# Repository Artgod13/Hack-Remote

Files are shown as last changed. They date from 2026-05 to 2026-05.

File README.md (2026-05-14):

# Hack-Remote
A cool remote that lets you control RF signals with a CC1101 module.
It has been specifically designed with customibilty in the code and ease of use in mind.
(Be careful to follow all radio laws in your area of jurisdiction)


 ---
 How this works is when you plug it into a power source to turn it on, you open up to a menu of different Mhz frequencies. At this menu you can scroll through different Mhz frequencies and click the rotary encoder switch to send out you're desired signal. I also added a signal called 676767 (Really funny I know). When you choose this signal it sends out the same message on 50 randomly chosen Mhz frequencies on at a time in quick succession to "test" RF signal receivers. I have made the code simple and easy to understand so that someone can go in and add their own desired Mhz frequencies and messages.
 
 ---
 I decided to make this, as I am constantly surrounded by RF receivers and transmitors. So why not build a simple device that is kinda like a flipper zero, and can manipulate/work with these RF signals. (Also flipper zeros are super expensive so if you want to make one but for like only RF here you go!)
 
 ---
 # Build Instructions:
Assembling the Hack Remote is very simple, all you need is a soldering iron, solder, 3d printed parts, PCB board, and all the parts in the BOM. First get the PCB board and place the compoments all facing up, and solder them onto their designated spots one by one. Next you want to flash the code onto the board, you do this by opening arduino IDE opening the code selecting the Xiao RP2040, and installing the Adafruit BusIO, AdafruitGFX Library, AdafruitSSD1306, RotaryEncoder, and SmartRC-CC1101-Driver-Lib Libraries. Then connnect you're board to the computer, and click upload on ArduinoIDE. After this get the Hack Remote bottom 3d printed part and put the assembled board onto it so that the Xiao usb-c end can be seen sticking out the power hole. Then screw the board on using 2 screws to make sure it stays in place. Finally put the Hack Remote Top on top of the bottom piece and use the rest of the screws to screw it in place. After all this work you should finally have a assembled Hack Remote ready to be used.

 ---
 # CAD MODEL:
 

These models were fully designed, and assembled in onshape.
https://cad.onshape.com/documents/6f64acb43278fcf02d95f203/w/43ea7b20cd107b410569e89b/e/a30772a52d9b3aa84b86adaa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

---
# PCB:



These were fully made on KiCad

---

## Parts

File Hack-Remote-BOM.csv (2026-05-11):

Item | Quantity | Unit Price ($) | Total Price ($) | URL
M3 x 8mm | 6 | 0.32 | 1.92 | https://accu-components.com/us/countersunk-socket-head-screws/5423-SSK-M3-8-A2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
EC11 Rotary Encoder | 1 | 2.27 | 2.27 | https://www.digikey.com/en/products/detail/bourns-inc/PEC11R-4220F-S0024/4499660
Seeed XIAO RP2040 | 1 | 3.99 | 3.99 | https://www.seeedstudio.com/XIAO-RP2040-v1-0-p-5026.html
0.91" 128x32 OLED Display | 1 | 3.73 | 3.73 | https://www.robotshop.com/products/091-inch-128x32-i2c-oled-display-blue
CC1101 | 1 | 8.99 | 8.99 | https://www.amazon.com/MELIFE-CC1101-Wireless-Antenna-Transceiver/dp/B0F7XGBX65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
Grand Total: 20.9

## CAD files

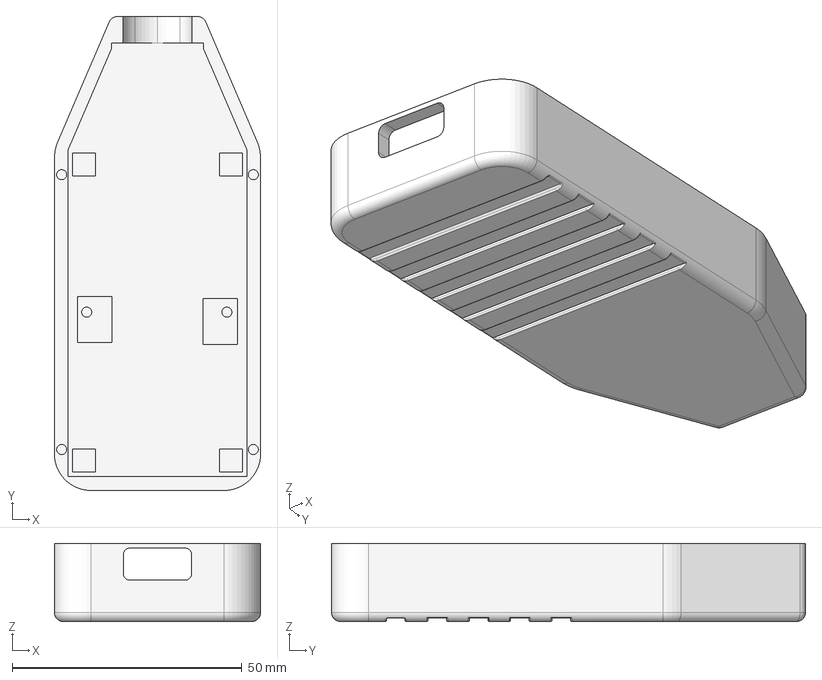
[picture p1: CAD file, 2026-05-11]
CAD/Hack-Remote-Top.step
44.9 x 103.1 x 17.0 mm

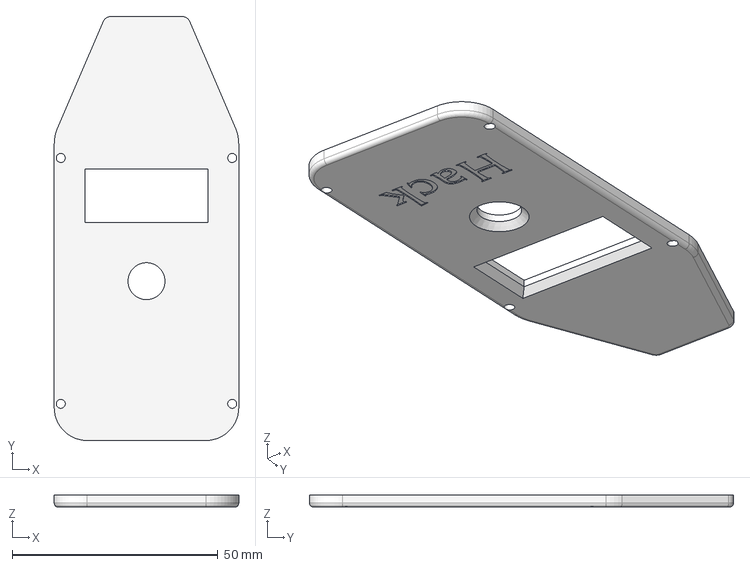
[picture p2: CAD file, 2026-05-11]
CAD/Hack-Remote-Bottom.step
44.9 x 103.1 x 3.00 mm

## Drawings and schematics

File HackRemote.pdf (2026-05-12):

# Hack Remote

# Arthur Bain 16 US

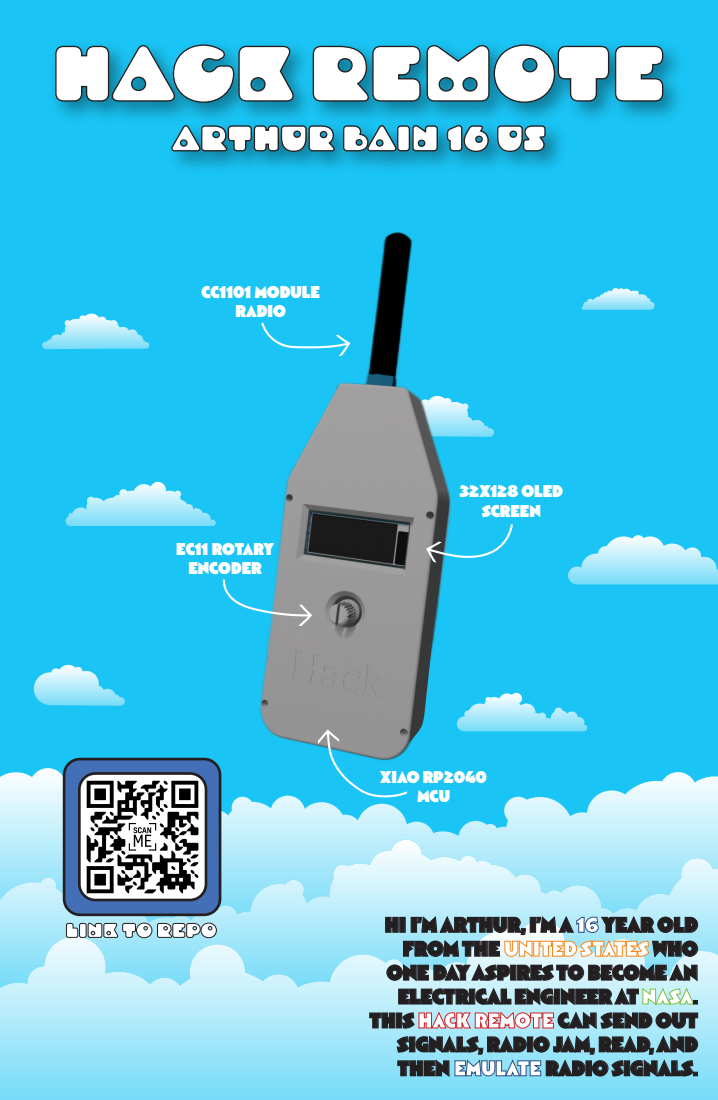
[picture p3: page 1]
CC1101 MODULE RADIO; 32X128 OLED SCREEN; EC11 ROTARY ENCODER; XIAO RP2040 MCU

LINK TO REPO

HI I’M ARTHUR, I’M A 16 YEAR OLD
FROM THE UNITED STATES WHO
ONE DAY ASPIRES TO BECOME AN
ELECTRICAL ENGINEER AT NASA.
THIS HACK REMOTE CAN SEND OUT
SIGNALS, RADIO JAM, READ, AND
THEN EMULATE RADIO SIGNALS.

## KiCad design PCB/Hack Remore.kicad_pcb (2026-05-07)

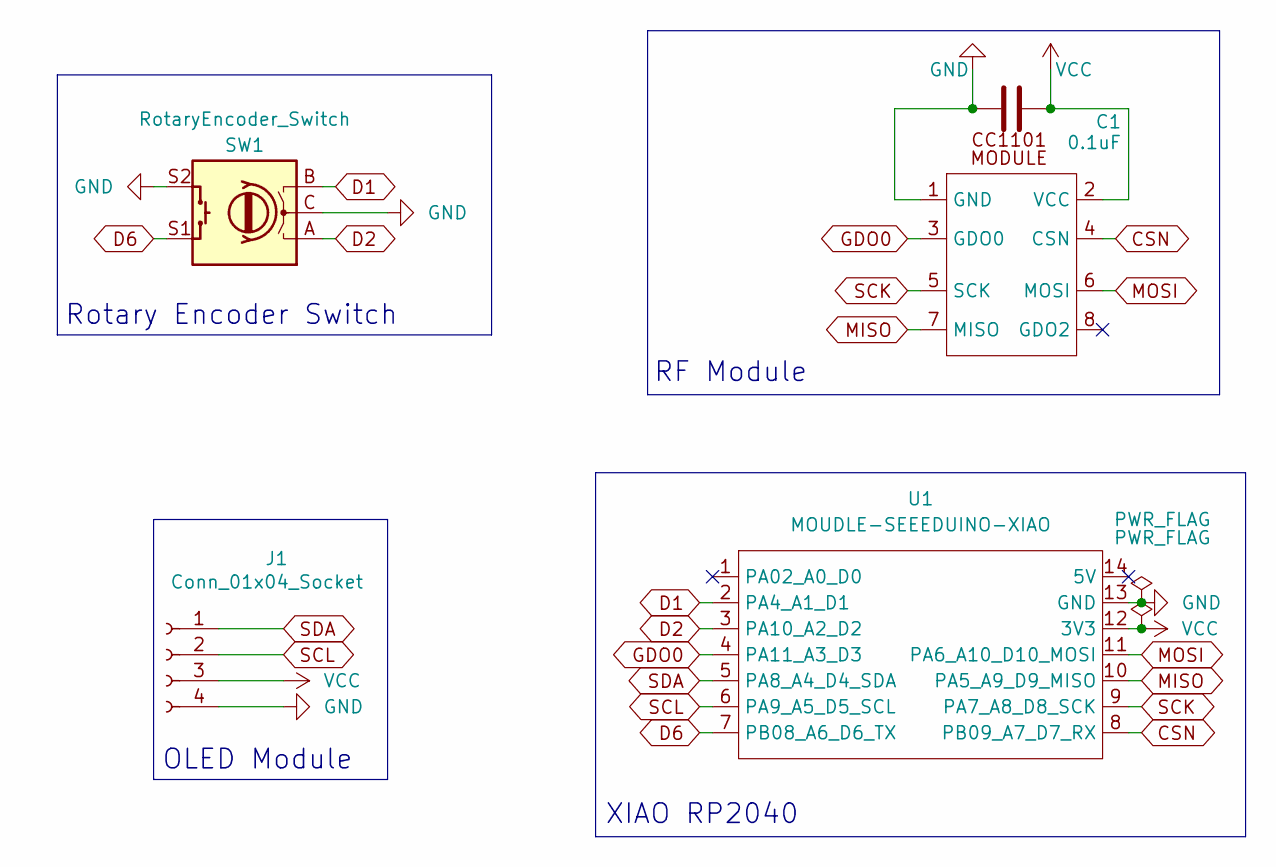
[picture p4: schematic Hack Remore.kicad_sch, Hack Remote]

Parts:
C1: 0.1uF; C_0805_2012Metric
J1: Conn_01x04_Socket; PinHeader_1x04_P2.54mm_Vertical
SW1: RotaryEncoder_Switch; RotaryEncoder_Alps_EC11E-Switch_Vertical_H20mm_MountingHoles
U1: MOUDLE-SEEEDUINO-XIAO; XIAO-Generic-Hybrid-14P-2.54-21X17.8MM
U3: PinSocket_2x04_P2.54mm_Vertical

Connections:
CSN: U1.8 (PB09_A7_D7_RX), U3.4 (CSN)
D1: SW1.B, U1.2 (PA4_A1_D1)
D2: SW1.A, U1.3 (PA10_A2_D2)
D6: SW1.S1, U1.7 (PB08_A6_D6_TX)
GDO0: U1.4 (PA11_A3_D3), U3.3 (GDO0)
GND: C1.2, J1.4, SW1.C, SW1.S2, U1.13 (GND), U3.1 (GND)
MISO: U1.10 (PA5_A9_D9_MISO), U3.7 (MISO)
MOSI: U1.11 (PA6_A10_D10_MOSI), U3.6 (MOSI)
SCK: U1.9 (PA7_A8_D8_SCK), U3.5 (SCK)
SCL: J1.2, U1.6 (PA9_A5_D5_SCL)
SDA: J1.1, U1.5 (PA8_A4_D4_SDA)
VCC: C1.1, J1.3, U1.12 (3V3), U3.2 (VCC)

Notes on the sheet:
RF Module
Rotary Encoder Switch
XIAO RP2040
OLED Module

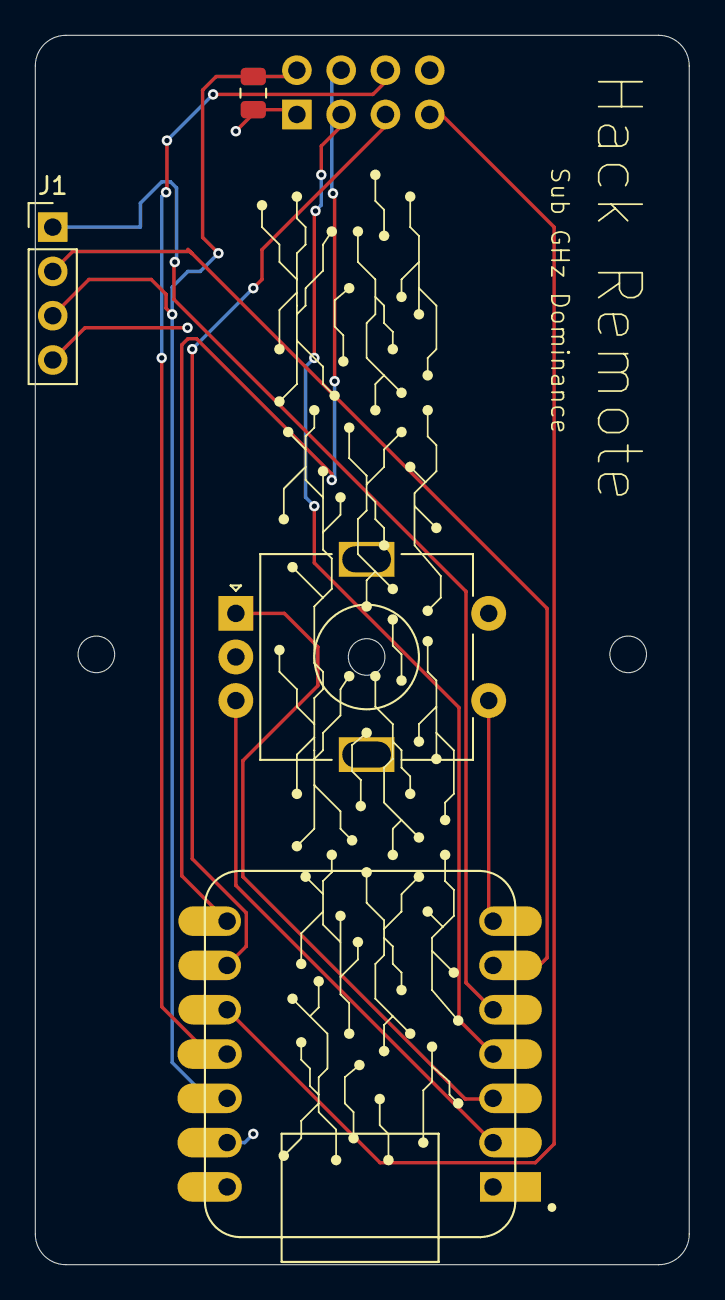
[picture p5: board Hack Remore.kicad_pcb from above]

Board: 2 copper layers, 37.5 x 70.5 mm, 5 parts (1 on the bottom side), 12 nets.

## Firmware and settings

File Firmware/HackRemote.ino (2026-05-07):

#include <Wire.h>
#include <SPI.h>
#include <Adafruit_GFX.h>
#include <Adafruit_SSD1306.h>
#include <RotaryEncoder.h>
#include <SmartRC-CC1101-Driver-Lib.h>

SmartRC_CC1101 radio;

//390 mHZ is the goal
//Be careful to follow all radio laws in your area of jurisdiction 
//YOU are responsible with what you do with this code not me

//OLED
#define SCREEN_WIDTH 128
#define SCREEN_HEIGHT 32
#define OLED_RESET -1
Adafruit_SSD1306 display(SCREEN_WIDTH, SCREEN_HEIGHT, &Wire, OLED_RESET)

//Rotary Encoder Switch
const int pinA = D2;
const int PinB = D1;
const int buttonPin = D6;

RotaryEncoder encoder(pinA, pinB,
RotaryEncoder::LatchModerTWO03);

//Frequencies
float channels[] = {
    390.0,
    391.0,
    392.0,
    393.0,
    395.0,
    400.0,
    433.0,
    433.92,
    434.0,
    676767.0
};

const int numChannels = sizeof(channels) /
sizeof(channels[0]);

float freq;
int currentIndex = 0;
int lastPos = 0;
bool lastButtonState = HIGH;

void drawScreen() {
    display.clearDisplay();
    display.setTextSize(1);
    display.setTextColor(SSD1306_WHITE);
    display.SetCursor(0, 0);
    display.Println("RF Channel Select");
    display.setTextSize(2);
    display.SetCursor(0, 14);
    display.Println(channels[currentIndex]);
    display.display();
}

void handleSelection() {
    display.clearDisplay();
    display.setTextSize(1);
    display.SetCursor(0, 0);
    display.Println("Selected:");
    display.setTextSize(2);
    display.SetCursor(0, 14);
    display.Println(channels[currentIndex]);
    display.display();
}


void setRadioFrequency() {
    Serial.begin(115200);
    radio.Init();
    radio.setMHZ(channels[currentIndex]);
    radio.SetTx();
}

void sendPacket() {
    if (channels[currentIndex] == 676767.0) {
        for (int x=0; x<50; x=x+1) {
            
            freq = random(39000, 45000) / 100.0;
            radio.setMHZ(freq);
            byte data[] = {0x00, 0x00, 0x00};
            radio.tx(data, sizeof(data));
            delay(10);

        }    
    } else {

        byte data[] = {0x00, 0x00, 0x00};
        radio.tx(data, sizeof(data));
        delay(1000);

    }
}

void setup() {
    
    Serial.begin(115200);
    radio.Init();
    radio.setMHZ(channels[currentIndex]);
    radio.SetRx();

    pinMode(buttonPin, INPUT_PULLUP);

    Wire.begin();

    if (!display.begin(SSD1306_SWITCHCAPVCC, 0x3C)) {
        while (1);
    }

    drawScreen();
}


void loop() {
    encoder.tick();

    int newPos = encoder.getPosition();

    if (newPos != lastPos) {
        if (newPos > lastPos) {
            currentIndex++;
        } else {
            currentIndex--;
        }

        if (currentIndex < 0) currentIndex = numChannels - 1;
        if (currentIndex >= numChannels) currentIndex = 0;

        lastPos = newPos;

        setRadioFrequency();
        drawScreen();
    }

    bool buttonState = digitalRead(buttonPin);

    if (lastButtonState == HIGH && buttonState == LOW) {
        sendPacket();
        handleSelection();
        delay(200);
    }

    lastButtonState = buttonState;
}

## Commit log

2026-05-08 Add assembly instructions for Hack Remote
    Added assembly instructions for the Hack Remote, detailing the components needed and the steps to complete the assembly process.
2026-05-08 Add build instructions for Hack Remote assembly
    Added build instructions for assembling the Hack Remote, including required components and steps for flashing the code.
2026-05-08 Update BOM with new items and URLs
    [Hack-RemoteBOM-Sheet1.csv]
2026-05-08 Update README with CAD model link
    Added a link to the CAD model documentation in the README.
